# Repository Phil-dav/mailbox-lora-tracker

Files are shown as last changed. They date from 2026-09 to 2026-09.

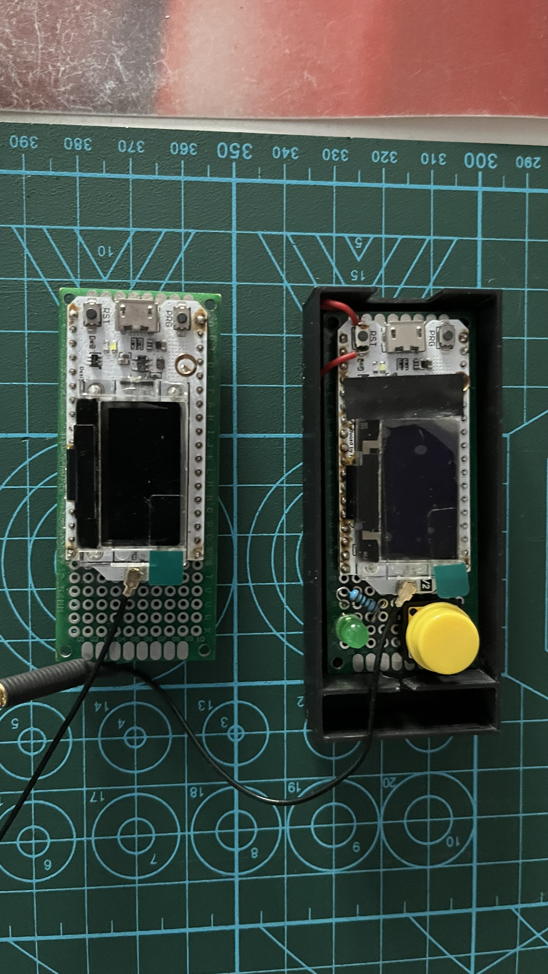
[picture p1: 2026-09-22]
Photos/Emetteur recepteur LORa.jpg

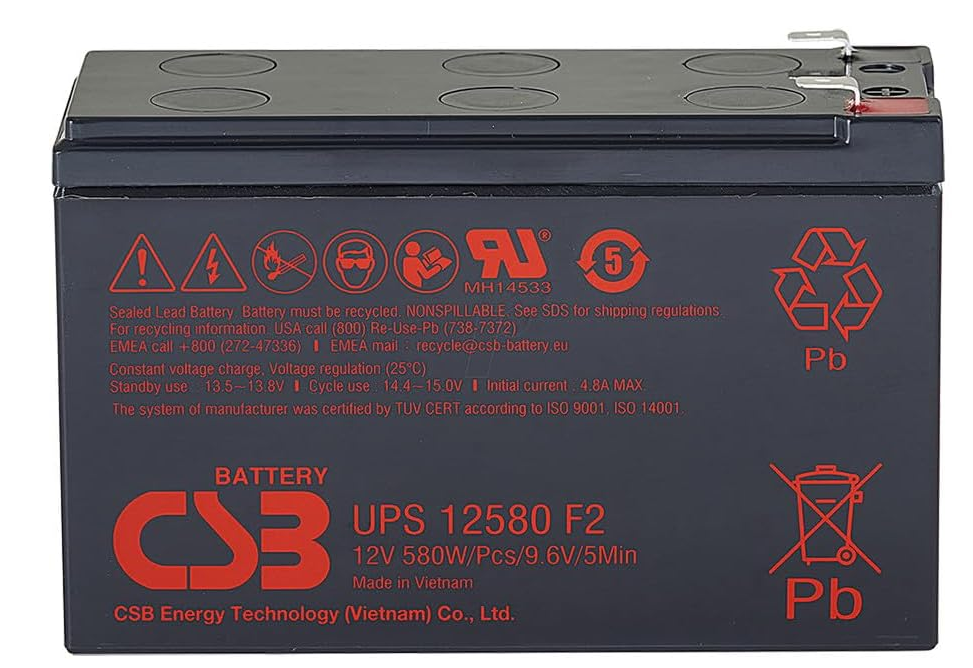
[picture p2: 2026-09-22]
Photos/CSB UPS12580 F2 AGM .png

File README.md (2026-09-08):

# Mailbox LoRa Tracker

A weight-sensing mailbox notifier built around a Heltec WiFi LoRa 32 (V2) and
an HX711 + 4 load cells. A door-triggered latching relay wakes the board with
zero standby current, it weighs whatever was just dropped in, sends the
result over LoRa to a receiver elsewhere in the house, waits for an ACK, then
cuts its own power.

Built for a shared/collective mailbox (multiple households behind one
postal-carrier door), where a simple door contact alone can't tell "someone
delivered to me" from "a neighbor's delivery, same door."

## How it works

```
Door opens (mechanical contact, no power needed)
  -> latching relay powers the board
  -> tare the HX711 (empty platform reference)
  -> wait for the door to close, or a safety timeout
  -> weigh again, with a settling/stability loop
     (absorbs shocks from a dropped/thrown package)
  -> if weight > threshold: send "COLIS:<grams>" over LoRa,
     wait for an ACK (bounded retries)
  -> cut its own power (transistor + relay), whatever happened above
```

Every branch converges on the same final power-cutoff step, so the board
always ends up switching itself off in bounded time, regardless of whether
a package was actually detected or an ACK came back.

## Hardware

- Heltec WiFi LoRa 32 V2 (ESP32 + SX127x), one per side (sender/receiver)
- HX711 + 4x 50kg half-bridge load cell sensors (bathroom-scale style)
- 2-relay latching power circuit (door contact triggers wake, transistor
  cuts power at end of cycle)
- 2nd door contact (independent GPIO) to detect when the door closes

### GPIO map (sender)

| GPIO | Function |
|---|---|
| 33 | Power cutoff (drives the relay-latch transistor) |
| 13 | 2nd door contact (detects door close) |
| 17 | HX711 DT |
| 23 | HX711 SCK |
| 5 / 27 / 19 / 18 | LoRa SPI (SCK / MOSI / MISO / NSS) — fixed on-module wiring |
| 14 | LoRa reset — fixed on-module wiring |
| 4 / 15 | OLED I2C (SDA / SCL) — fixed on-module wiring |
| 21 / 16 | OLED Vext / reset — fixed on-module wiring |

GPIO 34/35 are hardwired on the Heltec module to the SX127x's DIO2/DIO1 and
must never be reused for anything external.

## Repo contents

- `src/bin/courrier_emetteur.rs` — sender firmware (in the mailbox)
- `src/bin/courrier_recepteur.rs` — receiver firmware (indoors, mains-powered)
- `src/sx127x.rs` — minimal SX127x LoRa driver (SPI, ping/ack style)
- `KiCAD/Latch colis/` — schematic + PCB for the power-latch/relay board,
  plus etching files (single-sided, hand-etched)

> The schematic uses a couple of custom symbols/footprints (HX711 module,
> Heltec pinout) from a personal KiCad library that isn't included here yet
> — expect missing-footprint warnings if you open the project directly.

## Status

Weighing is calibrated and validated on the bench (13g to 2.25kg, <1% error
against a reference scale). Mechanical assembly (load cell mounting, door
contacts on the shared mailbox door) is still in progress.

## License

MIT — see [LICENSE](LICENSE).

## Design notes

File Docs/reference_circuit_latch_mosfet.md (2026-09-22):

# Circuit d'auto-maintien MOSFET pour l'émetteur boîte aux lettres

Référence trouvée le 22/08/2026, à étudier avant de câbler le circuit
d'alimentation de l'émetteur (contact ILS + MOSFET canal P).

## Lien principal

[Latching Power Switch Circuit (Auto Power Off Circuit) — Random Nerd Tutorials](https://randomnerdtutorials.com/latching-power-switch-circuit-auto-power-off-circuit-esp32-esp8266-arduino/)

Circuit spécifiquement conçu pour ESP32/ESP8266/Arduino, coupe le "+" de
l'alimentation (pas le "-").

**Composants** : MOSFET canal P (NDP6020P), transistor NPN 2N3904 (traducteur
de signal GPIO → grille du MOSFET), 2 diodes Schottky 1N5819, résistances
220kΩ / 2×100kΩ / 10kΩ / 220Ω.

**Principe** : le contact (bouton ou, dans notre cas, l'ILS) tire
momentanément la grille du MOSFET P vers le bas → la carte démarre → une GPIO
pilote un petit transistor NPN qui prend le relais pour maintenir la grille
basse → auto-maintien tant que la GPIO reste active → la carte coupe
elle-même l'alimentation en repassant la GPIO à l'état bas.

**Manque par rapport à notre besoin** : pas de condensateur pour ponter un
contact bref (le volet du courrier peut se rouvrir vite) — à ajouter
nous-mêmes en parallèle sur l'alimentation de la carte, en aval du MOSFET.

## Autres pages trouvées dans la même recherche (non étudiées en détail)

- [Push Button ON-OFF Soft Latch Circuits — Mosaic Industries](http://www.mosaic-industries.com/embedded-systems/microcontroller-projects/electronic-circuits/push-button-switch-turn-on/latching-toggle-power-switch)
- [Latching power switch uses momentary pushbutton — EDN](https://www.edn.com/latching-power-switch-uses-momentary-pushbutton/)
- [Soft Latching Power Circuits — Circuit Cellar](https://circuitcellar.com/resources/quickbits/soft-latching-power-circuits/)
- [Ditch The Switch: A Soft Latching Circuit Roundup — Hackaday](https://hackaday.com/2019/06/24/ditch-the-switch-a-soft-latching-circuit-roundup/)
- [Soft Latch Switch Circuit — circuits-diy.com](https://www.circuits-diy.com/soft-latch-switch-circuit/)
- [PBSEQ-D2 — CIRCUITSTATE Electronics](https://www.circuitstate.com/projects/pbseq-d2-soft-latching-power-sequencer-circuit-using-mosfets-amp-push-button/)

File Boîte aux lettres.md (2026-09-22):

# Boîte aux lettres LoRa — carte Heltec WiFi LoRa 32

Paquet : `lora-boite-lettres`
Carte : **Heltec WiFi LoRa 32** (confirmé le 19/08 via le programme C++ d'origine,
bibliothèque `heltec.h`), cible `xtensa-esp32-espidf`.

Deuxième paire de cartes (LilyGO T95_V1.1, radio potentiellement différente) :
voir `c:\rust\8`, projet séparé (nécessaire à cause de la limite de longueur
de chemin Windows avec ESP-IDF — voir mémoire `projet_piege_chemins_courts_espidf`).

## Contexte

4 cartes LoRa en main, dont 2 Heltec (celles-ci). Un premier essai en C++
avait fonctionné il y a longtemps (programme retrouvé le 19/08 :
`E:\Documents\Arduino\Boîte aux lettres\Programmes\LoRaEmisCourrier.ino` /
`LoRaRecCourrier.ino`), mais ne fonctionnait plus au moment de la reprise.
Repris intégralement en Rust (esp-rs).

## Étape actuelle — RÉSOLU le 19/08

Communication LoRa établie dans les deux sens (433 MHz, PA_BOOST +20 dBm,
AGC). Cause du blocage initial : mauvaise fréquence supposée (868 puis
915 MHz essayés par déduction, alors que la vraie valeur — 433 MHz — était
dans le programme C++ d'origine). Voir mémoire `projet_boite_lettres_lora`
pour le détail complet du diagnostic.

Programmes disponibles (`src/bin/`) :
- `emetteur.rs` / `recepteur.rs` — bancs de test (compteur, RSSI), à garder
- `courrier_emetteur.rs` / `courrier_recepteur.rs` — portage du vrai
  programme métier (capteur de lumière, "Courrier reçu...")
- `test_t95` a été déplacé vers `c:\rust\8` (carte différente)

## Prochaines étapes

1. Câbler la photorésistance réelle sur l'émetteur.
2. Circuit d'auto-maintien par MOSFET (décidé le 19/08, pas encore câblé/codé).
3. Éventuellement plusieurs points de détection (volet, porte, colis).

## État

Démarré le 19/08/2026. Fonctionnel, reste le câblage physique définitif.

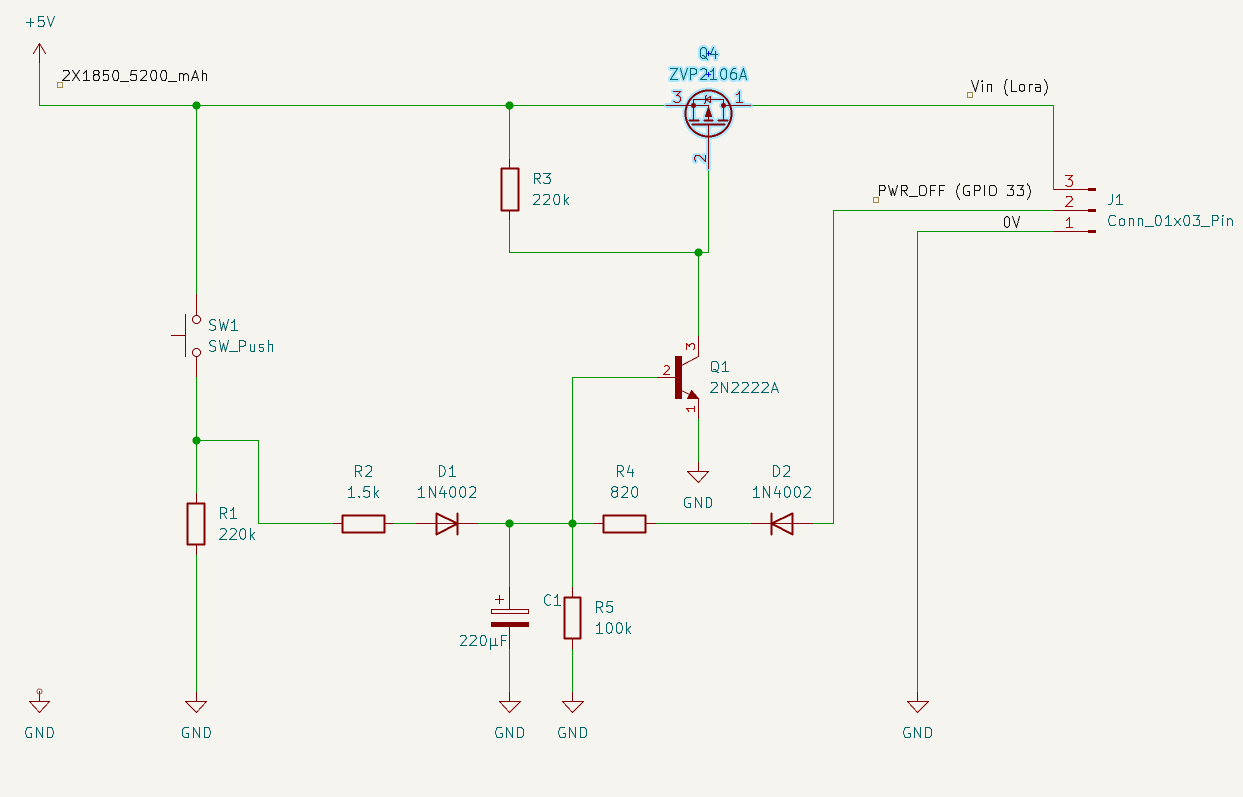
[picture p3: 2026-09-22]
KiCAD/Images/exemple latch cirsuit v1.png

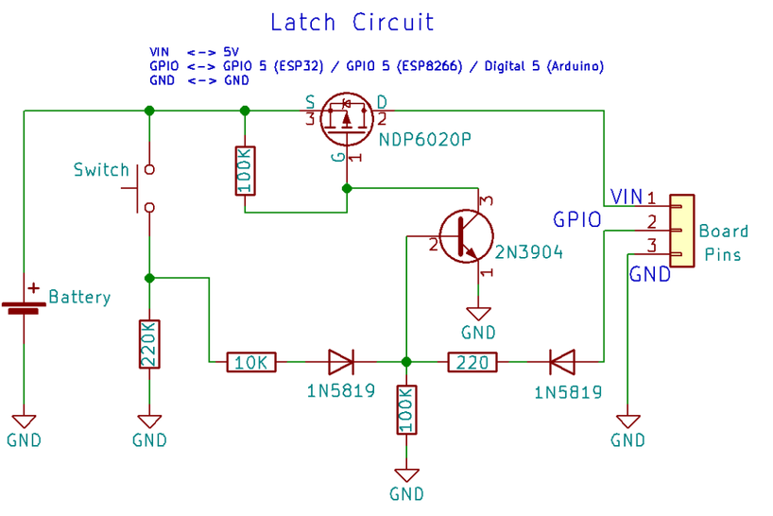
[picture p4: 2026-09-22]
KiCAD/Images/exemple latch cirsuit.png

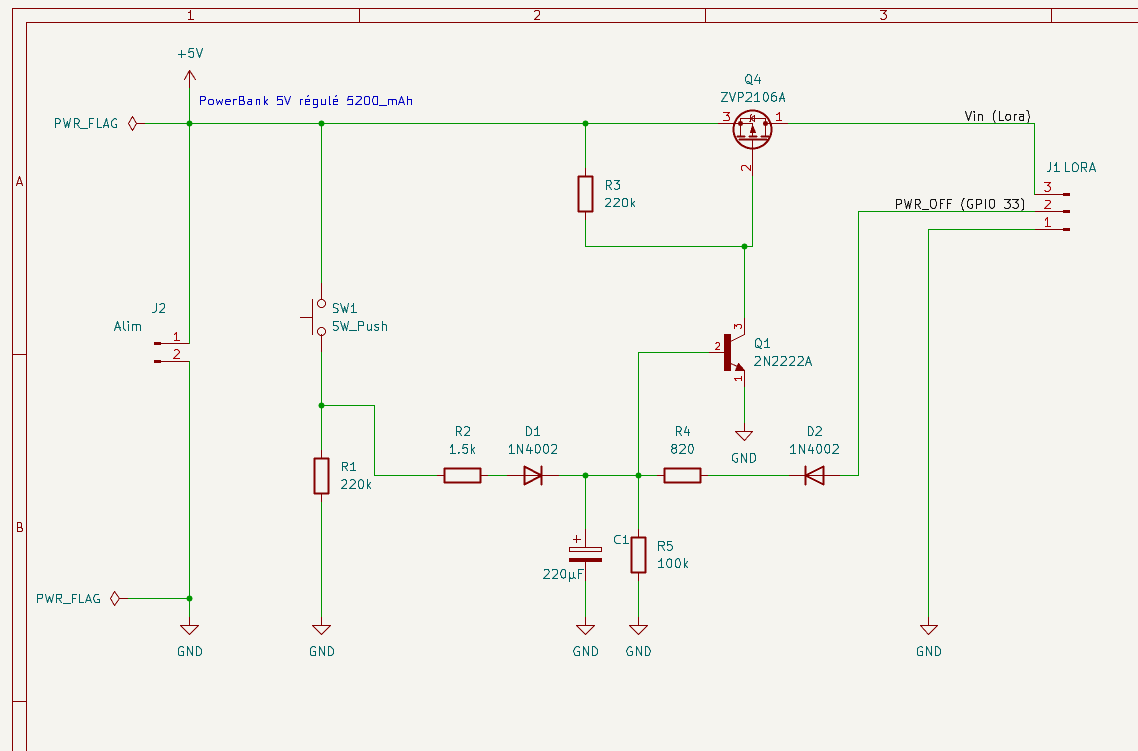
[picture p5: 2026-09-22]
KiCAD/Images/Latch MOSFET Lora final.png

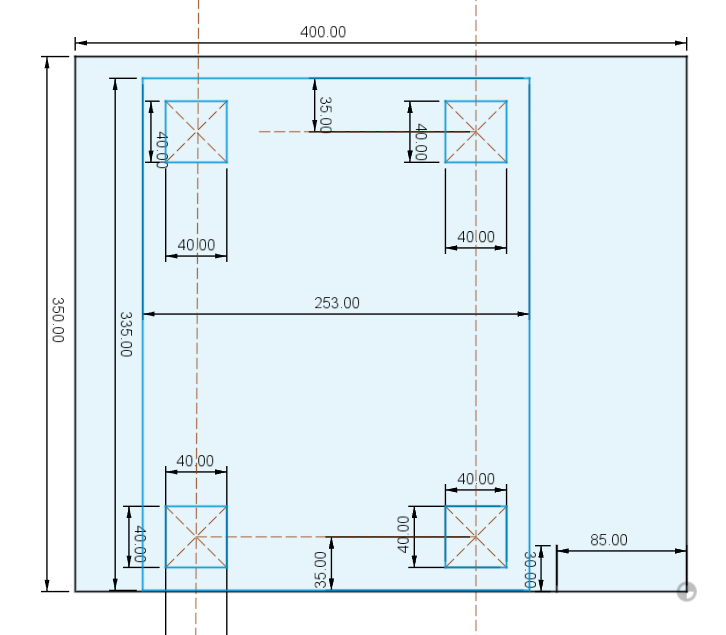
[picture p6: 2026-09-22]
Docs/plan_cotes_boite_lettres_plateau_pesee.png

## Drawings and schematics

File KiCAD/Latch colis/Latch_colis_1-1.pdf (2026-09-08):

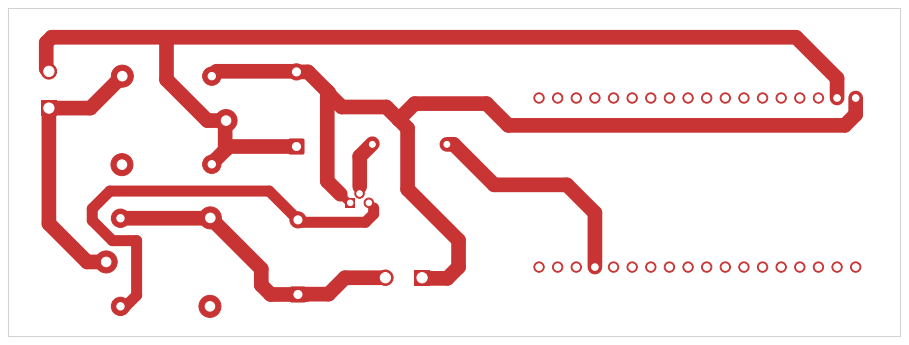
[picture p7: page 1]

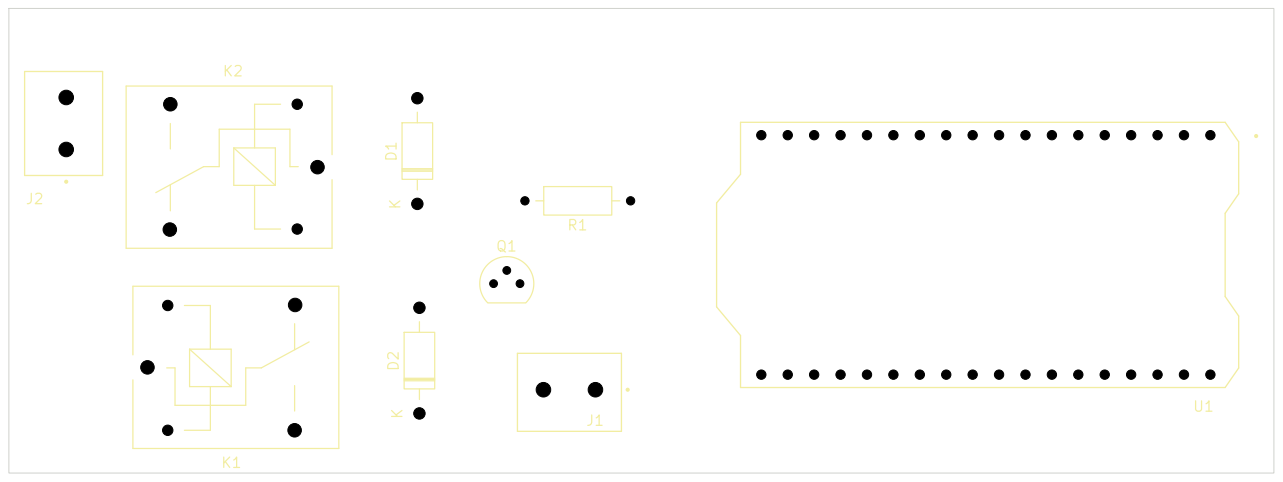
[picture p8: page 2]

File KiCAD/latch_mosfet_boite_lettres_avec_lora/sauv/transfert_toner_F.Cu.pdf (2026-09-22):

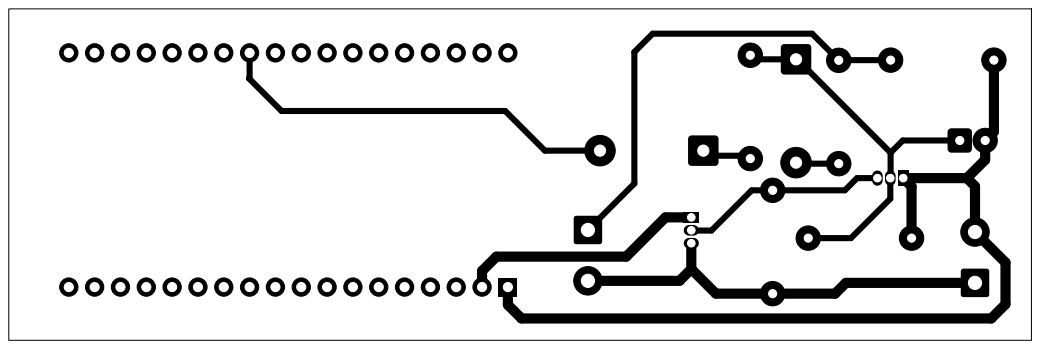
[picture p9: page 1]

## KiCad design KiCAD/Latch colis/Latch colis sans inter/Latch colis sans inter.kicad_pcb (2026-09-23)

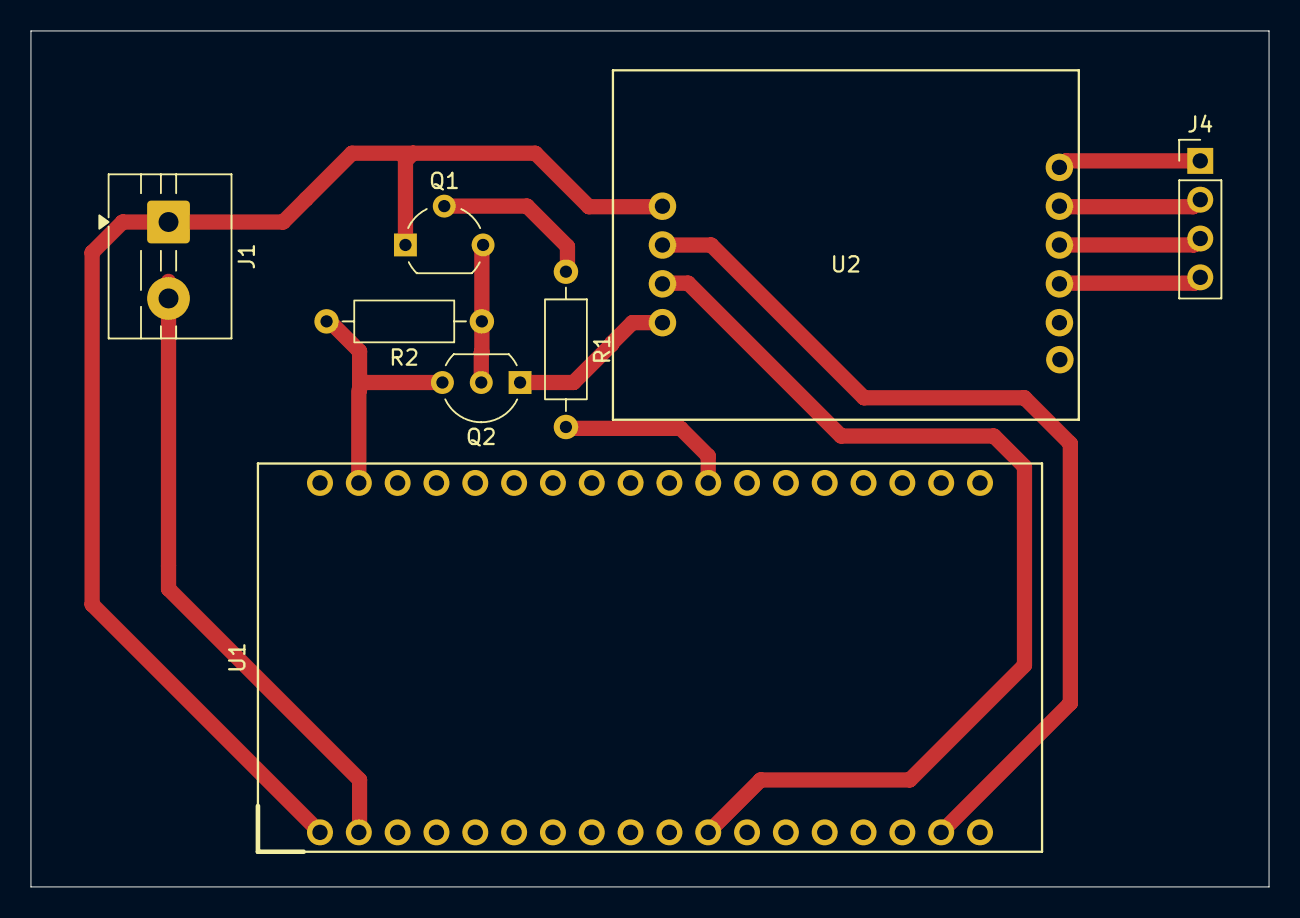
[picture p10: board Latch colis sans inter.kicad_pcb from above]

Board: 2 copper layers, 81.0 x 56.0 mm, 8 parts (0 on the bottom side), 13 nets.

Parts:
J1: KF301-2P
J4: Jauges; PinHeader_1x04_P2.54mm_Vertical
Q1: 2N2222A; TO-92_Wide
Q2: BS250; TO-92_Inline_Wide
R1, R2: 1k; R_Axial_DIN0207_L6.3mm_D2.5mm_P10.16mm_Horizontal
U1: Heltec_LoRa32_V2_RST_side; MODULE_ESP32_LORA_V2.0
U2: Module HX711; HX711_Module

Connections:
/+3.3V HX711: Q2.3 (S), R2.2, U1.20 (3V3)
/+5V: J1.2, U1.2 (5V)
/DT: U1.17, U2.8 (DT)
/SCK: U1.11 (23), U2.9 (SCK)
GND: J1.1, Q1.1, U1.1 (GND), U2.7 (GND)
unnamed: J4.1, U2.1 (E+)
unnamed: J4.2, U2.2 (E-)
unnamed: J4.3, U2.3 (A+)
unnamed: J4.4, U2.4 (A-)
unnamed: Q1.2, R1.1
unnamed: Q2.1 (D), U2.10 (VCC)
unnamed: Q1.3, Q2.2 (G), R2.1
unnamed: R1.2, U1.29 (33)

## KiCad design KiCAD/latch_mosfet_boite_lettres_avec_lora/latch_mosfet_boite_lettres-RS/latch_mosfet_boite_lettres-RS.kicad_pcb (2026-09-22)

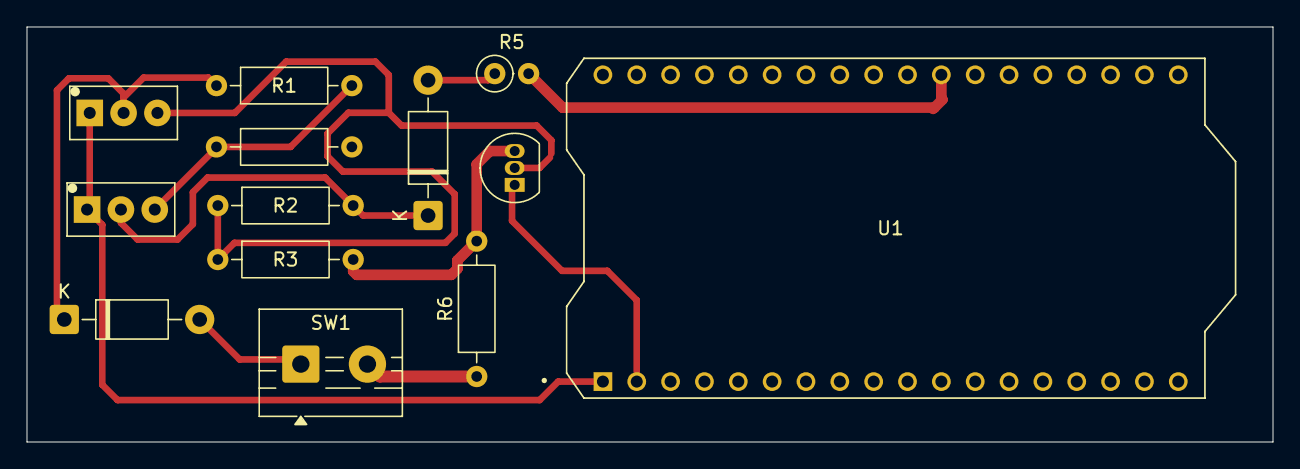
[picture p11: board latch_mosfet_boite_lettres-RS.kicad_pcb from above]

Board: 2 copper layers, 93.5 x 31.1 mm, 13 parts (0 on the bottom side), 11 nets.

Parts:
D1, D2: 1N4002; D_DO-41_SOD81_P10.16mm_Horizontal
Q1, Q2: 2N2222A; TO-92_Inline_Wide_5.08mm
Q4: ZVP2106A; TO-92_Inline
R1, R2, R3, R4, R6: R; R_Axial_DIN0207_L6.3mm_D2.5mm_P10.16mm_Horizontal
R5: R; R_Axial_DIN0207_L6.3mm_D2.5mm_P2.54mm_Vertical
SW1: SW_Push; TerminalBlock_MaiXu_MX126-5.0-02P_1x02_P5.00mm
U1: Heltec_LoRa32_V2_RST_side; MODULE_ESP32_LORA_V2.0

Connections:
+5V: Q4.3 (S), R3.2, R4.2, R6.2
GND: Q1.1, Q2.1, U1.1 (GND)
unnamed: D1.2 (A), SW1.1
unnamed: D1.1 (K), Q1.2, R1.1
unnamed: D2.2 (A), R5.1
unnamed: D2.1 (K), Q2.2, R2.2
unnamed: Q2.3, R1.2, R4.1
unnamed: Q4.1 (D), U1.2 (5V)
unnamed: Q1.3, Q4.2 (G), R2.1, R3.1
unnamed: R6.1, SW1.2
unnamed: R5.2, U1.29 (33)

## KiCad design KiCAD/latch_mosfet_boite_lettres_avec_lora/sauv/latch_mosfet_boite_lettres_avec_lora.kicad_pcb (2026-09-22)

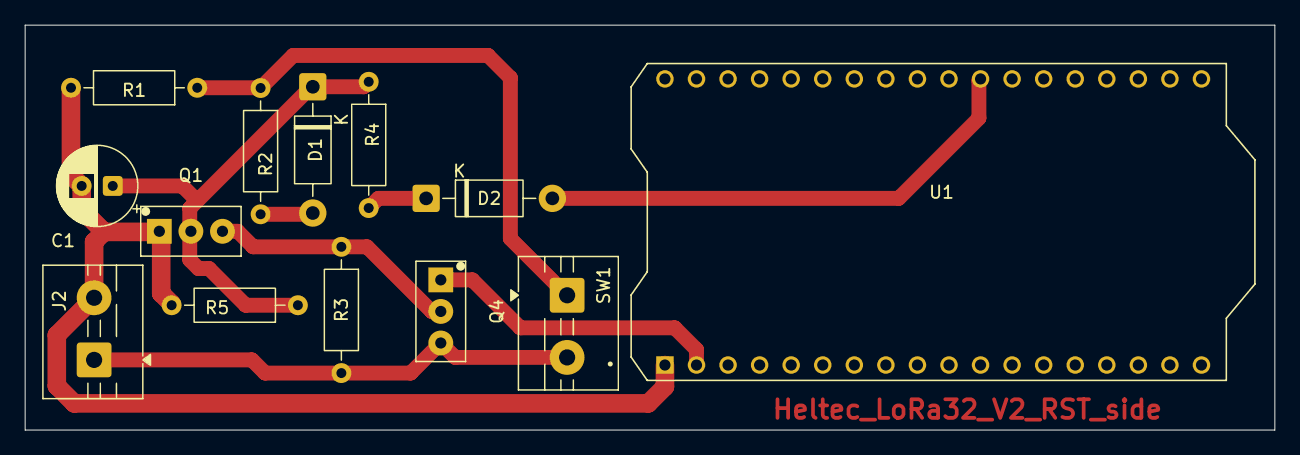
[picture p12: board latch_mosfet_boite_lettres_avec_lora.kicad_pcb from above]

Board: 2 copper layers, 100.6 x 32.6 mm, 13 parts (0 on the bottom side), 9 nets.

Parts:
C1: 220µF; CP_Radial_D6.3mm_P2.50mm
D1, D2: 1N4002; D_DO-41_SOD81_P10.16mm_Horizontal
J2: Alim; TerminalBlock_MaiXu_MX126-5.0-02P_1x02_P5.00mm
Q1: 2N2222A; TO-92_Inline_Wide_5.08mm
Q4: ZVP2106A; TO-92_Inline_Wide_5.08mm
R1, R3: 220k; R_Axial_DIN0207_L6.3mm_D2.5mm_P10.16mm_Horizontal
R2: 1.5k; R_Axial_DIN0207_L6.3mm_D2.5mm_P10.16mm_Horizontal
R4: 820; R_Axial_DIN0207_L6.3mm_D2.5mm_P10.16mm_Horizontal
R5: 100k; R_Axial_DIN0207_L6.3mm_D2.5mm_P10.16mm_Horizontal
SW1: SW_Push; TerminalBlock_MaiXu_MX126-5.0-02P_1x02_P5.00mm
U1: U1; MODULE_ESP32_LORA_V2.0

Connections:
+5V: J2.1, Q4.3 (S), R3.2, SW1.2
/PWR_OFF (GPIO 33): D2.2 (A), U1.29 (33)
/Vin (Lora): Q4.1 (D), U1.2 (5V)
GND: C1.2, J2.2, Q1.1, R1.2, R5.2, U1.1 (GND)
unnamed: D1.2 (A), R2.2
unnamed: C1.1, D1.1 (K), Q1.2, R4.1, R5.1
unnamed: D2.1 (K), R4.2
unnamed: Q1.3, Q4.2 (G), R3.1
unnamed: R1.1, R2.1, SW1.1

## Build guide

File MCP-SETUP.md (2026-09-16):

# Outils MCP (Context7, Firecrawl, KiCad)

Ce projet utilise 3 serveurs MCP pour étendre les capacités de Claude : Context7 (documentation de bibliothèques à jour), Firecrawl (recherche/lecture web, contourne certains blocages anti-robot), et un serveur KiCad (analyse de schémas/PCB, ERC/DRC, traçage de connexions).

La configuration (`.mcp.json`) est synchronisée par Dropbox et arrive donc automatiquement sur toutes les machines. Mais certains éléments sont propres à chaque ordinateur et doivent être réinstallés une fois par machine :
- Node.js (pour Context7 et Firecrawl)
- le cache npx (pour éviter des timeouts au premier lancement)
- les paquets Python installés dans le Python de KiCad (pour le serveur KiCad)

## Installation sur une nouvelle machine

1. Ouvrir un PowerShell à la racine de ce dossier ("Boite aux lettres").
2. Lancer :
   ```
   .\setup-mcp-tools.ps1
   ```
   Si Node.js vient d'être installé, le script s'arrête et demande de rouvrir un nouveau PowerShell puis de le relancer (le temps que le PATH se mette à jour).
3. Redémarrer VS Code.
4. Vérifier que les 3 serveurs (`context7`, `firecrawl`, `kicad`) apparaissent connectés.

## Détails / dépannage par outil

- **KiCad** : voir `../kicad-mcp-server/NOTES-INSTALLATION.md`. Si la version de KiCad diffère de 10.0, corriger le chemin dans `.mcp.json` (le script affiche le bon chemin).
- **Firecrawl** : la clé `FIRECRAWL_API_KEY` doit être présente dans `.mcp.json` (normalement déjà synchronisée par Dropbox — ne pas la recréer). Si erreur `ERR_MODULE_NOT_FOUND` au démarrage : cache npx corrompu, supprimer le dossier concerné dans `%LOCALAPPDATA%\npm-cache\_npx\` et relancer `npx -y firecrawl-mcp --help`.
- **Context7** : pas de clé nécessaire. Si timeout au premier lancement, relancer simplement `npx -y @upstash/context7-mcp@latest --help` une fois pour terminer le téléchargement.

`.mcp.json` contient une clé API (Firecrawl) — il est volontairement exclu de git (`.gitignore`), donc il ne se synchronise que par Dropbox, jamais par un `git push`.

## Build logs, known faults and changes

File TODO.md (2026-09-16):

# Registre de travail

## En cours : passage du réveil par contact de porte à un réveil temporisé (RTC deep-sleep)

**Motivation** : problèmes mécaniques pour fixer les contacteurs de porte, et
perçage interdit (location). Décision : abandonner le contact de porte,
réveiller la carte émettrice par timer RTC (deep-sleep ESP32), 2 fois/jour
(midi et 18h).

**Logique validée avec l'utilisateur** (voir conversation du 2026-09-13) :
- À chaque réveil : pesée avec boucle de stabilisation (comme aujourd'hui),
  puis si poids >= seuil : envoi LoRa `COLIS:<poids>` + attente ACK (comme
  aujourd'hui), sinon rien.
- Pas de mémorisation entre les cycles (pas de poids de référence, pas de
  flag "déjà notifié") : on notifie à *chaque* réveil tant qu'il y a du
  poids, même si c'est le même courrier non récupéré ou un 2e colis empilé.
  Confirmé explicitement : ça n'a aucune importance de distinguer
  ancien/nouveau courrier.
- Une fois la boîte vidée par l'utilisateur, le prochain réveil pèsera ~0 et
  ne notifiera pas — pas de mécanisme explicite nécessaire pour ça, c'est
  une conséquence naturelle de la logique ci-dessus.

**GRAFCET cible** (remplace l'attente de fermeture de porte par l'attente de
réveil RTC) :
```
X0 : DEEP SLEEP, RTC timer armé sur prochaine heure cible (12h/18h)
  -> réveil RTC ->
X1 : Réveil, init HX711, init LoRa
  ->
X2 : Pesée avec boucle de stabilisation (tolérance/délai max identiques à
     aujourd'hui)
  -> stabilisée ou timeout ->
   poids >= seuil ?
     oui -> X3 : envoi LoRa "COLIS:<poids>", attente ACK (essais bornés,
            identique à aujourd'hui)
     non -> rien
  -> (les deux branches reconvergent) ->
     retour X0 (deep sleep, prochain réveil programmé)
```

## Pas encore fait

- [ ] Implémenter la version deep-sleep RTC dans `src/bin/courrier_emetteur.rs`
      (sauvegarde de l'ancienne version déjà faite, voir ci-dessous —
      l'implémentation elle-même n'a pas encore commencé).
- [x] Question tranchée (2026-09-13) : le circuit de relais K1/K2 devient
      **inutile** avec le réveil RTC. Principe actuel confirmé par
      l'utilisateur pour mémoire : porte s'ouvre -> K2 (auto-maintien) se
      ferme et s'auto-alimente -> le 5V passe en série par le contact NF de
      K1 (fermé au repos) -> en fin de cycle, GPIO33 haut -> Q1 conduit ->
      excite K1 -> son contact NF s'ouvre -> coupe l'auto-maintien de K2 ->
      extinction totale. Ce mécanisme entier (K1, K2, Q1, contact de porte
      n°1) disparaît dans la version RTC : la carte reste alimentée en
      continu par la pile et gère elle-même son extinction via deep-sleep
      logiciel. Conséquence à traiter :
      - Le schéma KiCad (`KiCAD/Latch colis/`) doit être révisé pour retirer
        ce circuit (ou le neutraliser) une fois la nouvelle version actée.
      - Autonomie batterie à revalider : deep-sleep ESP32 (quelques dizaines
        de µA en continu) au lieu de coupure totale (0 µA) — compromis déjà
        discuté et accepté par l'utilisateur.
- [ ] Caler l'horloge RTC de l'ESP32 au démarrage (pas de source de temps
      fiable sans WiFi/NTP disponible sur la carte alimentée par pile) —
      à décider : dérive acceptée sur plusieurs mois, ou autre solution.
- [ ] Réfléchir à la valeur du seuil de poids dans ce nouveau contexte (le
      seuil actuel de 4 g visait à filtrer le bruit du capteur au repos ;
      probablement toujours valable mais à revalider une fois le nouveau
      flux en place).

## Sauvegardes effectuées

- `src/bin/courrier_emetteur-backups/courrier_emetteur_2026-09-13_avant-veille-rtc.rs`
  — copie de l'ancien firmware (réveil par contact de porte), avant toute
  modification. Dossier ignoré par git (`**/*-backups/`), conservé via
  Dropbox.

Rappel convention : toujours sauvegarder un fichier avant modification,
jamais d'écrasement direct (voir ce fichier + mémoire de session).

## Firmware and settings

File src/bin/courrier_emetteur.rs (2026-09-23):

use core::fmt::Write as _;
use esp_idf_svc::hal::delay::FreeRtos;
use esp_idf_svc::hal::gpio::{Input, Output, PinDriver, Pull};
use esp_idf_svc::hal::peripherals::Peripherals;
use esp_idf_svc::hal::spi::{config::Config as SpiConfig, SpiDeviceDriver, SpiDriverConfig};
use esp_idf_svc::hal::units::FromValueType;
use heapless::String;
use log::{info, warn};

use lora_boite_lettres::sx127x::{Reception, Sx127x};

// Programme "sans contact de porte" : la carte Heltec reste alimentée en
// continu sur pile et gère elle-même son cycle réveil/sommeil (deep-sleep
// RTC de l'ESP32), au lieu d'être réveillée par un contact mécanique sur la
// porte du facteur (abandonné : problèmes de fixation + interdiction de
// percer, logement en location). Séquence (voir schéma KiCad
// "Latch colis sans inter", circuit Q1/Q2 validé) :
//
//   Réveil RTC (toutes les INTERVALLE_VEILLE_US, corrigé à chaque échange
//   réussi, voir plus bas) -> mise sous tension du HX711 (GPIO33 -> Q1 -> Q2,
//   MOSFET P-channel côté haut) -> pesée avec boucle de stabilisation ->
//   poids >= seuil ? "COLIS:<g>" : "RIEN" -> envoi LoRa systématique et
//   attente d'accusé de réception (essais bornés), qui porte aussi la
//   correction d'horloge du récepteur -> coupure de l'alimentation du HX711,
//   mise en sommeil du module LoRa, puis deep-sleep de l'ESP32 jusqu'au
//   prochain réveil. Aucune mémorisation entre les cycles pour la décision
//   d'envoi (pas de poids de référence "avant/après", pas de "déjà
//   notifié") : on notifie à chaque réveil tant qu'il y a du poids sur le
//   plateau, décision actée avec l'utilisateur (peu importe qu'il s'agisse
//   du même courrier non récupéré ou d'un colis supplémentaire empilé).
//
// Pas d'écran OLED sur cette version : décision actée (consommation inutile
// sur une carte alimentée par pile, aucune indication utile une fois la
// boîte fermée).
const FREQUENCE_HZ: u32 = 433_000_000;
const TOURS_ATTENTE_ACK: u32 = 100; // 100 x 20ms = 2s
const DELAI_TOUR_MS: u32 = 20;
const MAX_ESSAIS: u32 = 3;

// --- Intervalle entre deux réveils ---
// Pas d'horloge temps réel ni de Wi-Fi/NTP sur cette carte (pile seule, hors
// de question d'ajouter du matériel/de la consommation juste pour l'horloge
// — voir [[projet_boite_lettres_lora]]). Valeur de repli utilisée tant
// qu'aucune correction n'a encore été reçue (premier réveil, ou échec de
// l'ACK) : 12h donne "deux fois par jour" à peu près, sans dérive corrigée.
//
// Correction d'horloge (10/09/2026) : à chaque réveil, l'émetteur envoie
// systématiquement un message (COLIS ou RIEN, voir plus bas) et écoute
// l'ACK. Le récepteur, lui, est sur secteur et synchronisé en NTP — il glisse
// à la fin de son ACK le nombre de secondes jusqu'au prochain 12h00/18h00
// (heure de Paris). Si cette correction est reçue, elle remplace
// INTERVALLE_VEILLE_US pour la durée de veille qui suit, ce qui recale
// l'émetteur sur l'heure murale à chaque échange réussi sans qu'il ait
// besoin de connaître l'heure lui-même. Voir courrier_recepteur.rs.
const INTERVALLE_VEILLE_US: u64 = 12 * 60 * 60 * 1_000_000;

// Plancher de sécurité pour la durée de veille corrigée : évite un réveil
// quasi immédiat (boucle qui viderait la batterie) si jamais la correction
// reçue tombait tout près de zéro (réveil arrivé à quelques secondes d'un
// 12h/18h pile).
const DUREE_VEILLE_MIN_US: u64 = 5 * 60 * 1_000_000;

// --- Pesée HX711 (voir mémoire projet, calibration validée à la main de
// 13g à 2,25kg avec un zéro frais : ~23,7 points bruts par gramme) ---
const PENTE_POINTS_PAR_GRAMME: f32 = 23.672;
const NB_ECHANTILLONS_HX711: u32 = 10;
// En dessous de ce poids (en grammes), on considère qu'il n'y a rien eu de
// déposé (bruit résiduel du capteur, jamais un vrai courrier).
const SEUIL_POIDS_G: f32 = 4.0;

// --- Boucle de stabilisation de la pesée (absorbe les chocs/rebonds d'un
// facteur qui pose ou jette le courrier) ---
const DELAI_MAX_STABILISATION_MS: u32 = 4_000;
const INTERVALLE_STABILISATION_MS: u32 = 300;
const TOLERANCE_STABILITE_G: f32 = 3.0;

// Temps de stabilisation du HX711 après remise sous tension (régulateur et
// oscillateur internes), avant que les mesures soient fiables.
const DELAI_ALIMENTATION_HX711_MS: u32 = 400;

// Zéro (tare) du HX711, conservé en mémoire RTC lente : survit au
// deep-sleep mais repart à sa valeur d'initialisation (sentinelle) à chaque
// véritable mise sous tension/reset. On ne tare donc qu'une seule fois, à
// la toute première mise en service, jamais à chaque réveil -- sinon un
// courrier déjà présent sur le plateau serait inclus dans le "zéro" et ne
// serait jamais détecté.
#[link_section = ".rtc.data"]
static mut ZERO_HX711: i32 = i32::MIN;

fn lire_brut_hx711(dt: &PinDriver<'_, Input>, sck: &mut PinDriver<'_, Output>) -> anyhow::Result<i32> {
    let mut tours_attente = 0;
    while dt.is_high() {
        FreeRtos::delay_ms(1);
        tours_attente += 1;
        if tours_attente > 1000 {
            warn!("HX711 ne répond pas (DT toujours haut après 1s) - vérifier le câblage");
            FreeRtos::delay_ms(500);
            tours_attente = 0;
        }
    }

    let mut valeur: u32 = 0;
    for _ in 0..24 {
        sck.set_high()?;
        valeur <<= 1;
        if dt.is_high() {
            valeur |= 1;
        }
        sck.set_low()?;
    }
    // 25e impulsion : fixe le gain à 128 (canal A) pour la prochaine mesure
    sck.set_high()?;
    sck.set_low()?;

    let valeur_signee: i32 = if valeur & 0x800000 != 0 {
        (valeur | 0xFF000000) as i32
    } else {
        valeur as i32
    };
    Ok(valeur_signee)
}

fn lire_moyenne_hx711(dt: &PinDriver<'_, Input>, sck: &mut PinDriver<'_, Output>) -> anyhow::Result<i32> {
    let mut somme: i64 = 0;
    for _ in 0..NB_ECHANTILLONS_HX711 {
        somme += lire_brut_hx711(dt, sck)? as i64;
    }
    Ok((somme / NB_ECHANTILLONS_HX711 as i64) as i32)
}

/// Convertit un écart brut HX711 en grammes, jamais négatif (un poids
/// négatif n'a pas de sens physique : c'est toujours du bruit/de la dérive).
fn poids_en_grammes(brut: i32, zero: i32) -> f32 {
    let ecart = (brut - zero) as f32 / PENTE_POINTS_PAR_GRAMME;
    if ecart < 0.0 {
        0.0
    } else {
        ecart
    }
}

fn main() -> anyhow::Result<()> {
    esp_idf_svc::sys::link_patches();
    esp_idf_svc::log::EspLogger::initialize_default();
    info!("Démarrage COURRIER EMETTEUR (réveil RTC, sans contact de porte)");

    let peripherals = Peripherals::take()?;

    // GPIO33 : commande la mise sous tension du HX711 (via Q1 -> Q2, MOSFET
    // P-channel côté haut) -- ce n'est plus une coupure de toute la carte
    // comme dans la version précédente à relais, seul le circuit balance
    // est concerné. A l'état bas au démarrage : HX711 éteint.
    let mut alimentation_hx711 = PinDriver::output(peripherals.pins.gpio33)?;
    alimentation_hx711.set_low()?;

    // HX711 : DT=GPIO17 (entrée, pull-up), SCK=GPIO23 (sortie). Broches
    // conformes au câblage réel du schéma "Latch colis sans inter".
    let dt = PinDriver::input(peripherals.pins.gpio17, Pull::Up)?;
    let mut sck = PinDriver::output(peripherals.pins.gpio23)?;
    sck.set_low()?;

    // --- Mise sous tension du HX711 et temps de stabilisation ---
    alimentation_hx711.set_high()?;
    FreeRtos::delay_ms(DELAI_ALIMENTATION_HX711_MS);

    // --- Zéro (tare) : une seule fois, jamais repris à chaque réveil (voir
    // commentaire sur ZERO_HX711) ---
    let zero = unsafe {
        if ZERO_HX711 == i32::MIN {
            let z = lire_moyenne_hx711(&dt, &mut sck)?;
            ZERO_HX711 = z;
            info!("Première mise en service : tarage HX711 effectué, zéro = {}", z);
            z
        } else {
            info!("Zéro HX711 repris de la mémoire RTC : {}", ZERO_HX711);
            ZERO_HX711
        }
    };

    // --- Module LoRa ---
    let lora_reset = PinDriver::output(peripherals.pins.gpio14)?;
    let spi_config = SpiConfig::new().baudrate(1.MHz().into());
    let lora_spi = SpiDeviceDriver::new_single(
        peripherals.spi2,
        peripherals.pins.gpio5,  // SCK
        peripherals.pins.gpio27, // MOSI
        Some(peripherals.pins.gpio19), // MISO
        Some(peripherals.pins.gpio18), // NSS
        &SpiDriverConfig::new(),
        &spi_config,
    )?;
    let mut lora = Sx127x::new(lora_spi, lora_reset);
    lora.init(FREQUENCE_HZ)?;
    info!("LoRa initialisé à {} Hz, prêt à émettre", FREQUENCE_HZ);

    // --- Pesée avec boucle de stabilisation (absorbe les chocs/rebonds
    // d'un facteur qui pose ou jette le courrier) ---
    let mut derniere_lecture = lire_moyenne_hx711(&dt, &mut sck)?;
    let mut stabilise = false;
    let mut attente_stabilisation_ms: u32 = 0;
    while attente_stabilisation_ms < DELAI_MAX_STABILISATION_MS {
        FreeRtos::delay_ms(INTERVALLE_STABILISATION_MS);
        attente_stabilisation_ms += INTERVALLE_STABILISATION_MS;
        let nouvelle_lecture = lire_moyenne_hx711(&dt, &mut sck)?;
        let ecart_g = ((nouvelle_lecture - derniere_lecture) as f32 / PENTE_POINTS_PAR_GRAMME).abs();
        derniere_lecture = nouvelle_lecture;
        if ecart_g < TOLERANCE_STABILITE_G {
            stabilise = true;
            break;
        }
    }
    let poids_final_g = poids_en_grammes(derniere_lecture, zero);
    if stabilise {
        info!("Pesée stabilisée après {} ms : {:.0} g", attente_stabilisation_ms, poids_final_g);
    } else {
        warn!("Pesée non stabilisée après {} ms, valeur retenue quand même : {:.0} g", attente_stabilisation_ms, poids_final_g);
    }

    // --- Message envoyé à chaque réveil, avec ou sans poids détecté (décision
    // actée avec l'utilisateur : pas de distinction ancien/nouveau courrier).
    // "RIEN" est envoyé même sans poids pour que le récepteur ait toujours
    // l'occasion de renvoyer la correction d'horloge (voir plus haut) ---
    let poids_confirme = poids_final_g >= SEUIL_POIDS_G;
    let poids_arrondi = poids_final_g.round() as i32;

    let mut message: String<32> = String::new();
    if poids_confirme {
        write!(message, "COLIS:{}", poids_arrondi).ok();
    } else {
        write!(message, "RIEN").ok();
    }
    let mut attendu: String<32> = String::new();
    write!(attendu, "ACK_{}", message.as_str()).ok();

    let mut ack_recu = false;
    let mut duree_veille_us = INTERVALLE_VEILLE_US;

    for essai in 1..=MAX_ESSAIS {
        match lora.envoyer(message.as_bytes()) {
            Ok(()) => info!("Envoyé : \"{}\" (essai {}/{})", message, essai, MAX_ESSAIS),
            Err(e) => {
                warn!("Échec d'envoi : {:?}", e);
                continue;
            }
        }

        lora.demarrer_ecoute()?;

        for _ in 0..TOURS_ATTENTE_ACK {
            if let Ok(Reception::Paquet { donnees, rssi_dbm }) = lora.recevoir() {
                let texte = core::str::from_utf8(&donnees).unwrap_or("");
                if texte.starts_with(attendu.as_str()) {
                    ack_recu = true;
                    info!("ACK reçu (RSSI {} dBm)", rssi_dbm);

                    // Correction d'horloge optionnelle : le récepteur ajoute
                    // ":<secondes jusqu'au prochain 12h/18h>" à la fin de
                    // l'ACK quand il connaît l'heure (NTP synchronisé).
                    if let Some(reste) = texte.get(attendu.len()..) {
                        if let Some(secondes_texte) = reste.strip_prefix(':') {
                            match secondes_texte.parse::<u64>() {
                                Ok(secondes) => {
                                    duree_veille_us = secondes
                                        .saturating_mul(1_000_000)
                                        .max(DUREE_VEILLE_MIN_US);
                                    info!(
                                        "Correction d'horloge reçue : prochain réveil dans {} s",
                                        secondes
                                    );
                                }
                                Err(_) => warn!("Correction d'horloge illisible dans l'ACK : \"{}\"", reste),
                            }
                        }
                    }
                    break;
                }
            }
            FreeRtos::delay_ms(DELAI_TOUR_MS);
        }

        if ack_recu {
            break;
        } else {
            warn!("Pas d'ACK (essai {}/{})", essai, MAX_ESSAIS);
        }
    }

    if !ack_recu {
        warn!(
            "Aucun ACK après {} essais, pas de correction d'horloge, intervalle par défaut ({} h)",
            MAX_ESSAIS,
            INTERVALLE_VEILLE_US / 3_600_000_000
        );
    }

    // --- Fin de cycle (convergence des deux branches) : coupure de
    // l'alimentation du HX711, mise en sommeil du module LoRa (sinon il
    // continue de consommer plusieurs mA tout seul pendant le deep-sleep de
    // l'ESP32), puis deep-sleep de l'ESP32 jusqu'au prochain réveil ---
    lora.dormir()?;
    alimentation_hx711.set_low()?;

    info!(
        "Fin de cycle, entrée en deep-sleep pour {:.1} h",
        duree_veille_us as f64 / 3_600_000_000.0
    );
    unsafe {
        esp_idf_svc::sys::esp_deep_sleep(duree_veille_us);
    }

    // Ne devrait jamais être atteint (esp_deep_sleep ne revient pas) :
    // sécurité au cas où, pour ne rien retenter d'ici la veille réelle.
    #[allow(unreachable_code)]
    loop {
        FreeRtos::delay_ms(1000);
    }
}

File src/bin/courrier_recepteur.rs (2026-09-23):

use core::fmt::Write as _;
use esp_idf_svc::eventloop::EspSystemEventLoop;
use esp_idf_svc::hal::delay::FreeRtos;
use esp_idf_svc::hal::gpio::PinDriver;
use esp_idf_svc::hal::i2c::{I2cConfig, I2cDriver};
use esp_idf_svc::hal::peripherals::Peripherals;
use esp_idf_svc::hal::spi::{config::Config as SpiConfig, SpiDeviceDriver, SpiDriverConfig};
use esp_idf_svc::hal::units::FromValueType;
use esp_idf_svc::nvs::EspDefaultNvsPartition;
use esp_idf_svc::sntp::{EspSntp, SyncStatus};
use heapless::String;
use log::{info, warn};

use embedded_graphics::{
    mono_font::{ascii::FONT_6X10, MonoTextStyle},
    pixelcolor::BinaryColor,
    prelude::*,
    text::Text,
};
use ssd1306::{prelude::*, I2CDisplayInterface, Ssd1306};

use lora_boite_lettres::sx127x::{Reception, Sx127x};
use lora_boite_lettres::temps;

// Programme définitif du récepteur : écoute en continu (sur secteur, pas de
// contrainte d'énergie), répond par un ACK dès réception d'un message
// "COLIS:<grammes>" ou "RIEN" de l'émetteur, avant de rester en écoute.
//
// Correction d'horloge pour l'émetteur (10/09/2026) : l'émetteur n'a pas
// d'horloge propre (pas question d'ajouter du matériel/de la conso batterie
// juste pour ça) et dort par intervalle fixe (~12h), qui dérive lentement par
// rapport à l'heure murale. Le récepteur, lui, est sur secteur et peut se
// synchroniser en NTP sans contrainte. Donc : à chaque réveil de l'émetteur,
// qui envoie toujours un message (COLIS ou RIEN) et écoute l'ACK, le
// récepteur calcule ici combien de secondes il reste jusqu'au prochain 12h00
// ou 18h00 (heure de Paris) et glisse ce nombre à la fin de l'ACK. L'émetteur
// n'a plus qu'à l'utiliser comme durée de veille au lieu de sa constante fixe
// -> auto-correction de la dérive à chaque échange, sans horloge ni composant
// supplémentaire côté émetteur. Voir [[projet_boite_lettres_lora]].
const FREQUENCE_HZ: u32 = 433_000_000;

fn main() -> anyhow::Result<()> {
    esp_idf_svc::sys::link_patches();
    esp_idf_svc::log::EspLogger::initialize_default();
    info!("Démarrage COURRIER RECEPTEUR");

    let peripherals = Peripherals::take()?;

    // --- Wi-Fi + NTP (uniquement pour connaître l'heure murale, voir
    // commentaire en tête de fichier). Non bloquant : si la connexion échoue
    // (réseau introuvable, mauvais mot de passe...), le récepteur continue
    // de fonctionner normalement, juste sans correction d'horloge à donner à
    // l'émetteur (celui-ci retombe alors sur son intervalle fixe par défaut).
    let sys_loop = EspSystemEventLoop::take()?;
    let nvs = EspDefaultNvsPartition::take()?;
    let mut sntp = None;
    match lora_boite_lettres::wifi::connecter(peripherals.modem, sys_loop, nvs) {
        Ok(wifi) => {
            info!("Wi-Fi connecté, démarrage de la synchro NTP");
            sntp = Some(EspSntp::new_default()?);
            // `wifi` doit rester en vie tout le programme (sinon la connexion
            // retombe) : on la laisse fuiter volontairement, le récepteur ne
            // s'arrête jamais.
            core::mem::forget(wifi);
        }
        Err(e) => warn!("Wi-Fi indisponible ({:?}), pas de correction d'horloge possible", e),
    }

    let mut oled_rst = PinDriver::output(peripherals.pins.gpio16)?;
    oled_rst.set_high()?;
    FreeRtos::delay_ms(10);
    oled_rst.set_low()?;
    FreeRtos::delay_ms(10);
    oled_rst.set_high()?;
    FreeRtos::delay_ms(10);

    let i2c_config = I2cConfig::new().baudrate(400.kHz().into());
    let i2c = I2cDriver::new(
        peripherals.i2c0,
        peripherals.pins.gpio4,
        peripherals.pins.gpio15,
        &i2c_config,
    )?;
    let interface = I2CDisplayInterface::new(i2c);
    let mut display = Ssd1306::new(interface, DisplaySize128x64, DisplayRotation::Rotate0)
        .into_buffered_graphics_mode();
    let ecran_disponible = display.init().is_ok();
    let style = MonoTextStyle::new(&FONT_6X10, BinaryColor::On);

    let lora_reset = PinDriver::output(peripherals.pins.gpio14)?;
    let spi_config = SpiConfig::new().baudrate(1.MHz().into());
    let lora_spi = SpiDeviceDriver::new_single(
        peripherals.spi2,
        peripherals.pins.gpio5,  // SCK
        peripherals.pins.gpio27, // MOSI
        Some(peripherals.pins.gpio19), // MISO
        Some(peripherals.pins.gpio18), // NSS
        &SpiDriverConfig::new(),
        &spi_config,
    )?;
    let mut lora = Sx127x::new(lora_spi, lora_reset);
    lora.init(FREQUENCE_HZ)?;
    lora.demarrer_ecoute()?;
    info!("LoRa initialisé à {} Hz, en écoute", FREQUENCE_HZ);

    if ecran_disponible {
        display.clear(BinaryColor::Off).ok();
        Text::new("Module LoRa ok!", Point::new(0, 8), style)
            .draw(&mut display)
            .ok();
        Text::new("En attente du facteur...", Point::new(0, 24), style)
            .draw(&mut display)
            .ok();
        display.flush().ok();
    }

    let mut nb_recus: u32 = 0;

    loop {
        match lora.recevoir() {
            Ok(Reception::Paquet { donnees, rssi_dbm }) => {
                let texte = core::str::from_utf8(&donnees).unwrap_or("(non-UTF8)");
                info!("Reçu : \"{}\" (RSSI {} dBm)", texte, rssi_dbm);

                // Le message a la forme "COLIS:<grammes>" (poids mesuré par
                // le HX711 côté émetteur) ou "RIEN" (réveil sans courrier,
                // envoyé quand même pour permettre la correction d'horloge
                // ci-dessous à chaque cycle, pas seulement quand il y a du
                // courrier).
                let poids_g: Option<i32> = texte
                    .strip_prefix("COLIS:")
                    .and_then(|reste| reste.parse::<i32>().ok());
                let message_valide = poids_g.is_some() || texte == "RIEN";

                // Répond par un ACK dès qu'un message valide est reçu, avant
                // de reprendre l'écoute. Si l'heure est connue (NTP
                // synchronisé), on ajoute à la fin le nombre de secondes
                // jusqu'au prochain réveil (12h/18h) pour que l'émetteur
                // recale sa propre veille dessus.
                if message_valide {
                    let correction_s = sntp
                        .as_ref()
                        .filter(|s| s.get_sync_status() == SyncStatus::Completed)
                        .and_then(|_| {
                            std::time::SystemTime::now()
                                .duration_since(std::time::UNIX_EPOCH)
                                .ok()
                        })
                        .and_then(|d| chrono::DateTime::from_timestamp(d.as_secs() as i64, 0))
                        .map(|dt| temps::vers_heure_paris(dt.naive_utc()))
                        .map(temps::secondes_jusqu_au_prochain_reveil);
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

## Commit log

2026-09-08 Initial commit: weight-sensing mailbox notifier (Heltec + HX711 + LoRa)
    Sender/receiver firmware, power-latch relay schematic/PCB, and load-cell
    weighing logic validated on the bench.
    [Latch colis.kicad_pcb, Latch colis.kicad_sch]
2026-09-16 Passage au reveil par minuterie RTC, bibliotheques KiCad partagees, outils MCP
    - Firmware courrier_emetteur : reveil profond par minuterie RTC au lieu du
    contact de porte, tarage HX711 persistant en memoire RTC, notification
    sans distinction nouveau/ancien courrier
    - Variante "Latch colis sans inter" du schema KiCad, empreintes partagees
    (fp-lib-table) et PDF de brochage Heltec ajoutes
    - Registre de travail (TODO.md) et espace de travail VS Code multi-dossiers
    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
    [Latch colis sans inter.kicad_pcb, Latch colis sans inter.kicad_sch, Latch colis.kicad_pcb]
2026-09-22 Fusion boite-aux-lettres-lora : ajout docs, photos, variantes KiCad, binaires de test
    - Docs/ : plan cotes boîte aux lettres, pinout Heltec, datasheet jauge 50kg, référence latch
    - KiCAD : 4 variantes schémas latch MOSFET (v1, NE555, avec_lora, RS) + images références
    - KiCAD Latch colis : fichiers PCB/SCH mis à jour (09-11/09), gravure actualisée
    - KiCAD Symboles : bibliothèque Heltec LoRa32 V2
    - src/bin : emetteur_test_1s, recepteur_test_1s, test_hx711
    - src/archive : historique des premières versions emetteur/recepteur
    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
    [Latch colis.kicad_pcb, Latch colis.kicad_sch, latch_mosfet_boite_lettres NE555.kicad_pcb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]
2026-09-23 Nettoyage ERC (no_connect) et reduction connecteur J4 a 4 broches
    Suite a l'abandon des contacts de porte (design "sans inter"), les 2
    signaux en trop du connecteur J4 n'ont plus lieu d'etre.
    [Latch colis sans inter.kicad_pcb, Latch colis sans inter.kicad_sch]
2026-09-23 Retire l'email personnel de Cargo.toml (reintroduit par erreur, depot public)
2026-09-23 Restaure la veille RTC (regressee par la fusion) et ajoute la correction d'horloge via le recepteur
    - courrier_emetteur.rs : restauration de la version deep-sleep RTC/sans
    contact de porte (la fusion precedente avait reintroduit par erreur
    l'ancienne version a relais). Envoie desormais "RIEN" a chaque reveil sans
    poids (au lieu de rien), pour toujours declencher l'echange ACK.
    - courrier_recepteur.rs : connexion Wi-Fi + NTP (non bloquante), calcule a
    chaque reception le nombre de secondes jusqu'au prochain 12h00/18h00 (heure
    de Paris) et le glisse a la fin de l'ACK.
    - courrier_emetteur.rs : utilise cette correction comme duree de deep-sleep
    au lieu de l'intervalle fixe de 12h, av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
    [Latch colis sans inter.kicad_pcb]
2026-09-23 Synchro fichiers Wi-Fi/NTP/correction d'horloge depuis C:\rust
    [Latch colis sans inter.kicad_pcb]
2026-09-23 Corrige courrier_emetteur.rs (merge automatique avait reintroduit un bloc de l'ancienne structure)
    [courrier_emetteur.rs]
